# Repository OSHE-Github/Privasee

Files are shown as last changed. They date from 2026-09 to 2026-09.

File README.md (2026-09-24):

# Privasee

There are multiple different types of cameras. Detecting with them can be done in a combination of different ways. Some of these way include, but are not limited too detecting the infrared light pulses, reading the Radio Frequency and a handful of other waysPrivasee is a two semester project intended to locate and detect cameras. Additionally, the device itself aims to be low-cost, mobile, and efficient for detection. In other words, the device should be able to scan an area such as a hotel room and indicate to the user if there is a hidden camera. The basis of what to detect for hidden cameras boils down to infrared, radio frequencies, and possibly mac addresses. Infrared is a common trait of hidden cameras since this allows cameras to operate and record in low visibility. Radio frequency is used by hidden cameras to transmit data back to the owner. Mac addresses involve picking up packets sent in the area and displaying the signal strength and address of the device.



# Current State


The current prototype includes:
  
  - IR Detection
  - Mac Adress Reading 
  - RF detection (?)

  The system operates as a standalone or works with a laptop to detect cameras
  
# Features
## Infared Detection
  

Many imaging and sensing systems make use of infrared (IR) light for active detection. While standard full-color cameras rely on visible light, some systems emit IR pulses and measure their reflection to detect objects or changes in the environment. Other systems, such as thermal imaging, instead detect existing heat sources and do not require emitted signals.

This circuit focuses on detecting active IR pulses from an external source.

Using the logic shown in the diagram above, the system monitors for the presence of an incoming IR signal and responds when a valid pulse is detected.

The circuit below implements this detection mechanism. An IR sensor (photodiode or phototransistor) converts incoming infrared light into an electrical signal. This signal is then conditioned and amplified so it can be evaluated against a threshold.\

When the detected signal exceeds this threshold:
  - The circuit switches states
  - A control response is triggered
  - A buzzer is activated to indicate detection

This design allows the system to reliably detect IR pulses and convert them into a clear, real-time output signal. When integrated with a larger control loop, it can be used as an input for more complex sensing or decision-making systems.
  
  

## Radio Frequency
  Radio Frequency (RF) was chosen due to increasing amount of cameras connecting to Wifi. While connected to WiFi, cameras can capture vidoo and trasmit it. This makes it detectable for as it 
  emits oscilalitng EWF waves that can be picked up. For this semester of the project, the prototype aims to target active cameras transmitting over 2.4GHz.

  

### Antenna
  In order to start detecting signal a proper antenna is needed. The antenna will be responsible for picking up wifi signals that devices emit. In this case, the antenna must tuned to a
  resonance frequency of 2.4GHz. With proper tuning, the antenna will pick up these wifi signals more efficiently and this will result in a higher AC voltage.

### Diode Rectification
  Achieving high AC voltage make it much easier to amplify and notice difference in detection. A limiting factor of this AC voltage is that it is operating at 2.4GHz which is much more than
  what the LM358 can support. To amend this, a BAT41 diode was used to help rectify the AC voltage into DC voltage. Advantages of this include readable and processable voltage by the Op amp.
  Downsides of this diode involve voltage drops which results in a weaker signal. A capacitor and resistor is needed in parallel with the rectified diode voltage output in order to “hold” the
  DC voltage so it can be amplified by the OP Amp.

### Amplfication
  As mentioned earlier, amplification is needed to help create a more readable voltage. This it utilizing an LM358 Op amp in a non-inverting configuration. 
  
  RF Results

## MAC Address Reading
Many hidden cameras will connect to the internet to upload the videos/pictures they capture. The ESP32's built in WiFi Promiscuous mode can be used to capture packet information and do further analysis on packets in the area. This system only uses information available in IEEE 802.11 packet headers, such as the sending MAC address and data segment length. The ESP32 will also take an RSSI (Received Signal Strength Indicator) measurement when the packet is received. This data helps seperate each packet by a unique device identifier, and enables tracking of the changing signal stregth over time.
The ESP is unable to differentiate between device types by using this information, limiting this features ability to identify hidden cameras. Though this is the case, the MAC addresses and RSSI can be used to located devices in the area that are connected to the internet. 

# Tools Used

### Software
  Arduino IDE  
  Python  
  KiCad  
  OnShape  
  Git Desktop  

### Hardware
  Solder Iron Station  
  Wire Cutters  
  Wire Crimpers  

# Assembly Instructions

## RF

### Antenna
The SMA mount will be used as basis for the ground plane
Cut two lengths of copper wire to 33mm  
Cut longer than intended length adjustments/tuning can be made afterwords  
Solder one length of the copper wire to the signal pin forming a 90 degree angle  
Solder another length to the SMA mount leg pointing in the opposite direction of the signal pin  

### Board Assembly
Using the schematic for RF assemble the parts on to the protoboard  
Minimize amount of solder used components connecting into V+  
This includes the antenna, BAT41 diode, 1nF capacitor, 1Mohm resistor, and LM358 Op amp  

# Other catagories

### RF Flaws
A big issue with the RF side of this project revolved around a poor testing environment. The testing environment of RF was near an oscilloscope scope which constantly emitted EMF waves. These radiating waves from the oscilloscope cause the antenna on the breadboard to pick up a much stronger signal that what was expected on a 2.4ghz band. This error was caught later on in the semester and resulted in a more rushed prototype of what is currently featured above. While the concept of RF detection is proved, there are underdeveloped areas of RF which include antenna creation and op amp gain. Additionally factors such as parasitic capacitance and type of boards used were not analyzed as well.

The current graph shows some post error data of the current prototype. While this does display a correlation of RF being detected, the gain actual gain is really low. This is mainly due to the BAT41 diode used which did rectify the voltage but resulted in a 0.3V drop. Due to passive antennas not outputting much voltage, there was not a large amount of rectified voltage to be amplified by the op amp. 

#Appendex
- [Bill of Materials (BOM)](Documentation/BOM.md)

# Refrences
[1] “IR cameras - how they work and how to use them,” Sensorland.com, 2026. https://www.sensorland.com/HowPage105.html (accessed Apr. 20, 2026).

‌

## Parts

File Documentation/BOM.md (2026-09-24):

# Bill of Materials (BOM)

This Bill of Materials summarizes all components required to assemble the Privasee Device.

---

## Main Board Module

| # | Part Name | Individual Cost | QTY | Total Cost | Link |
| - | --- | --- | --- | --- | ---- |
| 1 | ESP32-C6 Dev Board | $8.00 | 1 | $8.00 | https://www.digikey.com/en/products/detail/espressif-systems/ESP32-C6-DEVKITM-1-N4/18667011 |
| 2 | Micro SD Breakout | $7.50 | 1 | $7.50 | https://www.digikey.com/en/products/detail/adafruit-industries-llc/254/5761230 |
| 3 | Switch | $0.36 | 1 | $0.36 | https://www.digikey.com/en/products/detail/same-sky-formerly-cui-devices/SLW-129956-4A-RA-N-D/24399223 |
| 4 | 3.3V Buck Booster | $3.12 | 1 | $3.12 | https://www.digikey.com/en/products/detail/dfrobot/DFR0568/9559258 |
| 5 | AA Battery Holder | $1.80 | 1 | $1.80 | https://www.digikey.com/en/products/detail/mpd-memory-protection-devices/BC2AAW/2190080 |

**Subtotal: $20.78**

---

## RF Module

| # | Part Name | Individual Cost | QTY | Total Cost | Link |
| - | --- | --- | --- | --- | ---- |
| 1 | Antenna Mount | $3.86 | 1 | $3.86 | https://www.digikey.com/en/products/detail/molex/0732511153/11305709 |
| 2 | Copper Wire Spool | ~$7.00 | 1 | ~$7.00 | Lab Resource |
| 3 | SMA M-M Adapter | $6.95 | 1 | $6.95 | https://www.amazon.com/dp/B0BWJGQC9M |
| 4 | BAT41 Diode | $0.15 | 2 | $0.30 | https://www.digikey.com/en/products/detail/stmicroelectronics/BAT41/603518 |
| 5 | 1nF Capacitor | $0.38 | 1 | $0.38 | https://www.digikey.com/en/products/detail/kemet/C320C102K3G5TA/6656382 |
| 6 | 1M Resistor | $0.10 | 1 | $0.10 | https://www.digikey.com/en/products/detail/stackpole-electronics-inc/CF14JT1M00/1741316 |
| 7 | 10k Resistor | $0.10 | 1 | $0.10 | https://www.digikey.com/en/products/detail/stackpole-electronics-inc/CF14JT10K0/1741265 |
| 8 | 1k Resistor | $0.10 | 1 | $0.10 | https://www.digikey.com/en/products/detail/stackpole-electronics-inc/CF14JT1K00/1741314 |
| 9 | Header Pin Pack | $3.29 | 1 | $3.29 | https://www.digikey.com/en/products/detail/aries-electronics/14-0600-21/49895 |
|10 | Protoboard | ~$5.00 | 1 | ~$5.00 | Lab Resource |

**Subtotal: ~$27.08**

---

## IR Module

| # | Part Name | Individual Cost | QTY | Total Cost | Link |
| - | --- | --- | --- | --- | ---- |
| 1 | Photodiode | $2.49 | 1 | $2.49 | https://www.digikey.com/en/products/detail/advanced-photonix/PDB-C134F/480578 |
| 2 | 25Ω Resistor | $0.10 | 1 | $0.10 | https://www.digikey.com/en/products/detail/stackpole-electronics-inc/MR3FT25L0/1650256 |
| 3 | 100Ω Resistor | $0.10 | 1 | $0.10 | (N/A) |
| 4 | 1MΩ Resistor | $0.10 | 1 | $0.10 | (N/A) |
| 5 | LM358 Op Amp | $0.99 | 1 | $0.99 | https://www.digikey.com/en/products/detail/texas-instruments/LM358N-NOPB/6264 |

**Subtotal: $3.78**

---

## Total Summary

| Category | Cost |
| --- | --- |
| Main Board | $20.78 |
| RF Module  | ~$27.08 |
| IR Module  | $3.78 |

### **Estimated Total Cost: ~$51.64**

---

## Notes

- RF subtotal corrected and expanded for missing components
- BAT41 diode quantity updated to match total cost
- Standardized resistor pricing where missing
- All links preserved for sourcing and procurement

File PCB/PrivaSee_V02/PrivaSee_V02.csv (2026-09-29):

Reference | Qty | Value | DNP | Exclude from BOM | Exclude from Board | Exclude from Simulation | Exclude from Position Files | Footprint | Datasheet
U6 | 1 | ESP32-C5-DevKitC-1 |  |  |  |  | ${EXCLUDE_FROM_POS_FILES} | PCM_Espressif:ESP32-C5-DevKitC-1 | https://docs.espressif.com/projects/esp-dev-kits/en/latest/esp32c5/esp32-c5-devkitc-1/user_guide.html
U4 | 1 | DFR0568 |  |  |  |  | ${EXCLUDE_FROM_POS_FILES} | Connector_PinSocket_2.54mm:PinSocket_2x02_P2.54mm_Vertical
U3 | 1 | 254 |  |  |  |  | ${EXCLUDE_FROM_POS_FILES} | Connector_PinHeader_2.54mm:PinHeader_1x08_P2.54mm_Vertical
U2 | 1 | LM358 |  |  |  |  | ${EXCLUDE_FROM_POS_FILES} | Package_DIP:DIP-8_W7.62mm_Socket | http://www.ti.com/lit/ds/symlink/lm2904-n.pdf
U1 | 1 | RC1602A |  |  | Excluded from board |  | ${EXCLUDE_FROM_POS_FILES} | Display:RC1602A | http://www.raystar-optronics.com/down.php?ProID=18
SW2 | 1 | SW_Push |  |  |  |  | ${EXCLUDE_FROM_POS_FILES} | Button_Switch_THT:SW_PUSH_6mm_H4.3mm
SW1 | 1 | Switch |  |  |  |  | ${EXCLUDE_FROM_POS_FILES} | Button_Switch_SMD:Nidec_Copal_CAS-120A | https://www.nidec-components.com/e/catalog/switch/cas.pdf
R9,R10 | 2 | 10k |  |  |  |  | ${EXCLUDE_FROM_POS_FILES} | Resistor_SMD:R_1206_3216Metric_Pad1.30x1.75mm_HandSolder
R8 | 1 | 100 ohm |  |  |  |  | ${EXCLUDE_FROM_POS_FILES} | Resistor_SMD:R_1206_3216Metric_Pad1.30x1.75mm_HandSolder
R7 | 1 | 10 |  |  |  |  | ${EXCLUDE_FROM_POS_FILES} | Resistor_SMD:R_1206_3216Metric_Pad1.30x1.75mm_HandSolder
R6 | 1 | RT0402BRE07100KL |  |  |  |  | ${EXCLUDE_FROM_POS_FILES} | Snapeda:RC0402N_YAG-L | RT0402BRE07100KL
R5 | 1 | 1 MOhm |  |  |  |  | ${EXCLUDE_FROM_POS_FILES} | Resistor_SMD:R_1206_3216Metric_Pad1.30x1.75mm_HandSolder
R4 | 1 | 100 Ohms |  |  |  |  | ${EXCLUDE_FROM_POS_FILES} | Resistor_SMD:R_1206_3216Metric_Pad1.30x1.75mm_HandSolder
R3 | 1 | 25 Ohms |  |  |  |  | ${EXCLUDE_FROM_POS_FILES} | Resistor_SMD:R_1206_3216Metric_Pad1.30x1.75mm_HandSolder
R2 | 1 | 470 Ohm |  |  |  |  | ${EXCLUDE_FROM_POS_FILES} | Resistor_SMD:R_1206_3216Metric_Pad1.30x1.75mm_HandSolder
R1 | 1 | 200 |  |  |  |  | ${EXCLUDE_FROM_POS_FILES} | Resistor_SMD:R_1206_3216Metric_Pad1.30x1.75mm_HandSolder
L1 | 1 | LQW15AN9N1H00D |  |  |  |  | ${EXCLUDE_FROM_POS_FILES} | Snapeda:INDC1006X60N
J7 | 1 | RF_TEST |  |  |  |  | ${EXCLUDE_FROM_POS_FILES} | TestPoint:TestPoint_THTPad_1.5x1.5mm_Drill0.7mm
J6 | 1 | IR_TEST |  |  |  |  | ${EXCLUDE_FROM_POS_FILES} | TestPoint:TestPoint_THTPad_1.5x1.5mm_Drill0.7mm
J5 | 1 | GND_TEST |  |  |  |  | ${EXCLUDE_FROM_POS_FILES} | TestPoint:TestPoint_Pad_1.0x1.0mm
J4 | 1 | VOUT_TEST |  |  |  |  | ${EXCLUDE_FROM_POS_FILES} | TestPoint:TestPoint_Pad_1.0x1.0mm
J3 | 1 | Conn_02x06_Odd_Even |  |  |  |  | ${EXCLUDE_FROM_POS_FILES} | Connector_PinHeader_2.54mm:PinHeader_2x06_P2.54mm_Vertical
J2 | 1 | Batt_Solder_Point |  |  |  |  | ${EXCLUDE_FROM_POS_FILES} | Connector_PinHeader_2.54mm:PinHeader_1x02_P2.54mm_Vertical
J1 | 1 | RFPC-SMA27-F |  |  |  |  | ${EXCLUDE_FROM_POS_FILES} | Snapeda:GRADCONN_RFPC-SMA27-F
D3 | 1 | Photodiode |  |  |  |  | ${EXCLUDE_FROM_POS_FILES} | Diode_THT:D_A-405_P2.54mm_Vertical_AnodeUp | https://www.diodes.com/assets/Datasheets/ds30396.pdf
D1 | 1 | BAT1504WH6327XTSA1 |  |  |  |  | ${EXCLUDE_FROM_POS_FILES} | JLCImport:BAT1504WH6327XTSA1 | https://wmsc.lcsc.com/wmsc/upload/file/pdf/v2/lcsc/2304061030_Infineon-Technologies-BAT1504WH6327XTSA1_C5380972.pdf
C3 | 1 | GJM1555C1H220FB01D |  |  |  |  | ${EXCLUDE_FROM_POS_FILES} | Snapeda:CAP_GJM1555C1H220FB01D_MUR-L | GJM1555C1H220FB01D
C2 | 1 | GJM1555C1H4R7CB01D |  |  |  |  | ${EXCLUDE_FROM_POS_FILES} | Snapeda:G-155_MUR-L | GJM1555C1H4R7CB01D
C1 | 1 | GJM1555C1HR22BB01D |  |  |  |  | ${EXCLUDE_FROM_POS_FILES} | Snapeda:CAPC1005X55N
BZ1 | 1 | Buzzer |  |  |  |  | ${EXCLUDE_FROM_POS_FILES} | Buzzer_Beeper:Buzzer_15x7.5RM7.6
BT1 | 1 | Battery |  |  | Excluded from board |  | ${EXCLUDE_FROM_POS_FILES} | Battery:BatteryHolder_Keystone_2462_2xAA

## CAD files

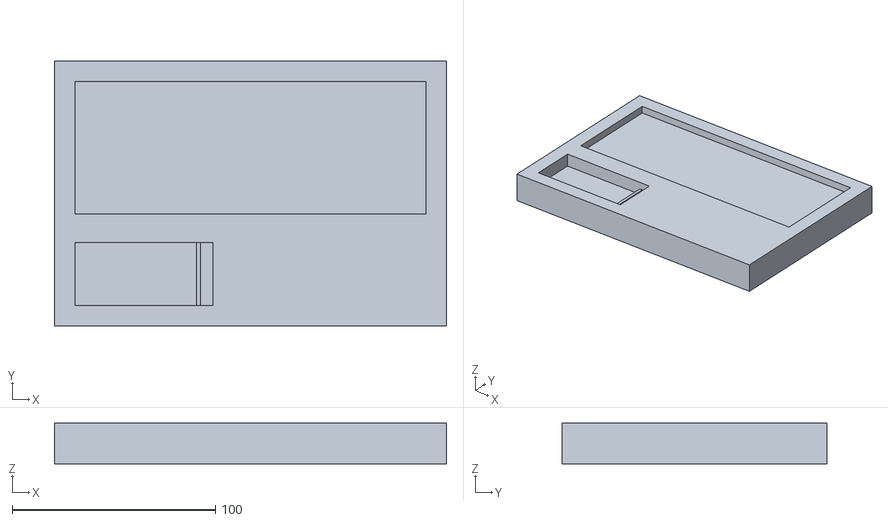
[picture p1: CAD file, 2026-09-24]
hardware/Breadboard_case.stl
193.1 x 130.4 x 20.0

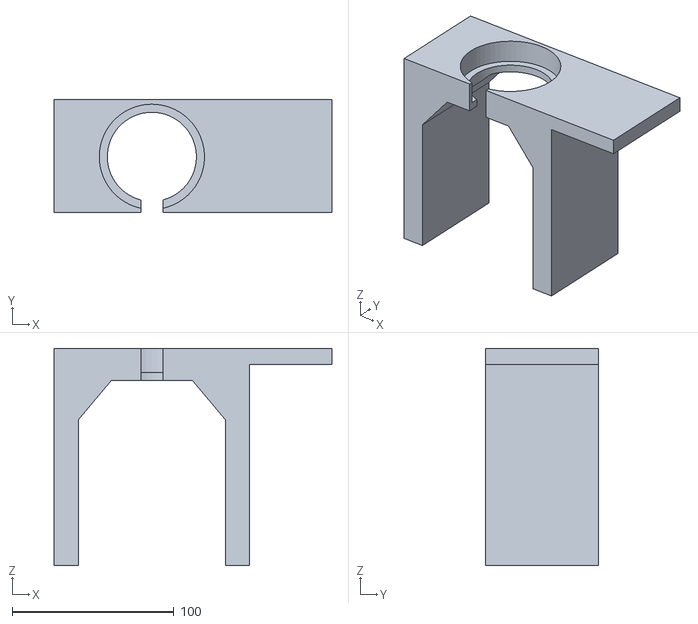
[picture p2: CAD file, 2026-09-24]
hardware/Magnfine_wave_amplifier.stl
171.7 x 69.7 x 134.3

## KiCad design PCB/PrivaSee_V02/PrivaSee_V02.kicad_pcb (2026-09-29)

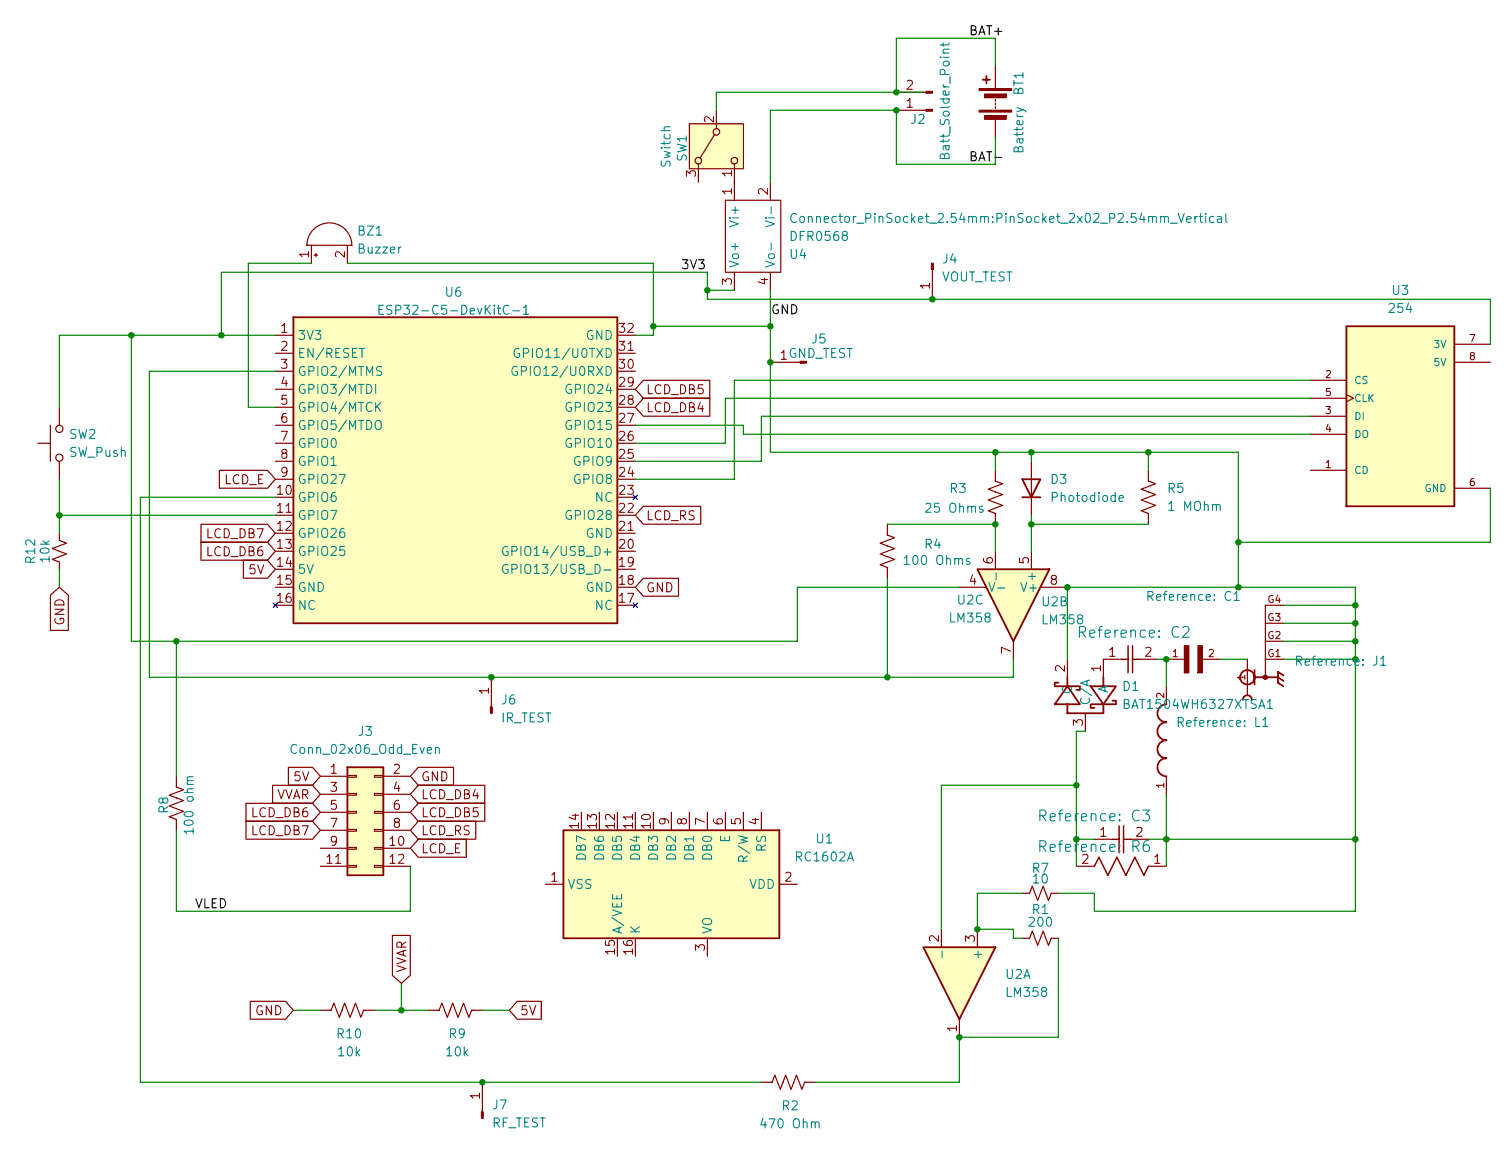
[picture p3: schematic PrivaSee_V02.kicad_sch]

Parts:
BT1: Battery; BatteryHolder_Keystone_2462_2xAA
BZ1: Buzzer; Buzzer_15x7.5RM7.6
C1: GJM1555C1HR22BB01D; CAPC1005X55N
C2: GJM1555C1H4R7CB01D; G-155_MUR-L
C3: GJM1555C1H220FB01D; CAP_GJM1555C1H220FB01D_MUR-L
D1: BAT1504WH6327XTSA1; Manufacturer Part BAT1504WH6327XTSA1; LCSC C5380972
D3: Photodiode; D_A-405_P2.54mm_Vertical_AnodeUp
J1: RFPC-SMA27-F; GRADCONN_RFPC-SMA27-F; PARTREV 1.0
J2: Batt_Solder_Point; PinHeader_1x02_P2.54mm_Vertical
J3: Conn_02x06_Odd_Even; PinHeader_2x06_P2.54mm_Vertical
J4: VOUT_TEST; TestPoint_Pad_1.0x1.0mm
J5: GND_TEST; TestPoint_Pad_1.0x1.0mm
J6: IR_TEST; TestPoint_THTPad_1.5x1.5mm_Drill0.7mm
J7: RF_TEST; TestPoint_THTPad_1.5x1.5mm_Drill0.7mm
L1: LQW15AN9N1H00D; INDC1006X60N
R1: 200; R_1206_3216Metric_Pad1.30x1.75mm_HandSolder
R2: 470 Ohm; R_1206_3216Metric_Pad1.30x1.75mm_HandSolder
R3: 25 Ohms; R_1206_3216Metric_Pad1.30x1.75mm_HandSolder
R4: 100 Ohms; R_1206_3216Metric_Pad1.30x1.75mm_HandSolder
R5: 1 MOhm; R_1206_3216Metric_Pad1.30x1.75mm_HandSolder
R6: RT0402BRE07100KL; RC0402N_YAG-L
R7: 10; R_1206_3216Metric_Pad1.30x1.75mm_HandSolder
R8: 100 ohm; R_1206_3216Metric_Pad1.30x1.75mm_HandSolder
R9, R10, R12: 10k; R_1206_3216Metric_Pad1.30x1.75mm_HandSolder
SW1: Switch; Nidec_Copal_CAS-120A
SW2: SW_Push; SW_PUSH_6mm_H4.3mm
U1: RC1602A
U2: LM358; DIP-8_W7.62mm_Socket
U3: 254; PinHeader_1x08_P2.54mm_Vertical; PARTREV Jul 31, 2013
U4: DFR0568; PinSocket_2x02_P2.54mm_Vertical
U6: ESP32-C5-DevKitC-1

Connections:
5V: J3.1, R9.2, U6.14 (5V)
/3V3: J4.1 (Pin_1_1), R8.1, SW2.2, U2.4 (V-), U3.7 (3V), U4.3 (Vo+), U6.1 (3V3)
/BAT+: BT1.1 (+), J2.2 (Batt+), SW1.2 (B)
/BAT-: BT1.2 (-), J2.1 (Batt-), U4.2 (Vi-)
/VLED: J3.12, R8.2
GND: BZ1.2 (-), C3.2, D1.2 (C), D3.2 (A), J1.G1, J1.G2, J1.G3, J1.G4, J3.2, J5.1 (Pin_1_1), L1.1, R3.1, R5.1, R6.1, R7.2, R10.1, R12.1, U2.8 (V+), U3.6 (GND), U4.4 (Vo-), U6.18 (GND), U6.32 (GND)
LCD_DB4: J3.4, U6.28 (GPIO23)
LCD_DB5: J3.6, U6.29 (GPIO24)
LCD_DB6: J3.5, U6.13 (GPIO25)
LCD_DB7: J3.7, U6.12 (GPIO26)
LCD_E: J3.10, U6.9 (GPIO27)
LCD_RS: J3.8, U6.22 (GPIO28)
unnamed: BZ1.1 (+), U6.5 (GPIO4/MTCK)
unnamed: C1.1, C2.2, L1.2
unnamed: C1.2, J1.1
unnamed: C2.1, D1.1 (A)
unnamed: C3.1, D1.3 (C/A), R6.2, U2.2 (-)
unnamed: D3.1 (K), R5.2, U2.5 (+)
unnamed: J6.1 (Pin_1_1), R4.2, U2.7, U6.3 (GPIO2/MTMS)
unnamed: J7.1 (Pin_1_1), R2.1, U6.10 (GPIO6)
unnamed: R1.2, R2.2, U2.1
unnamed: SW1.1 (C), U4.1 (Vi+)
unnamed: R1.1, R7.1, U2.3 (+)
unnamed: R3.2, R4.1, U2.6 (-)
unnamed: U3.5 (CLK), U6.26 (GPIO10)
unnamed: U3.2 (CS), U6.24 (GPIO8)
unnamed: U3.3 (DI), U6.25 (GPIO9)
unnamed: U3.4 (DO), U6.27 (GPIO15)
unnamed: R12.2, SW2.1, U6.11 (GPIO7)
VVAR: J3.3, R9.1, R10.2

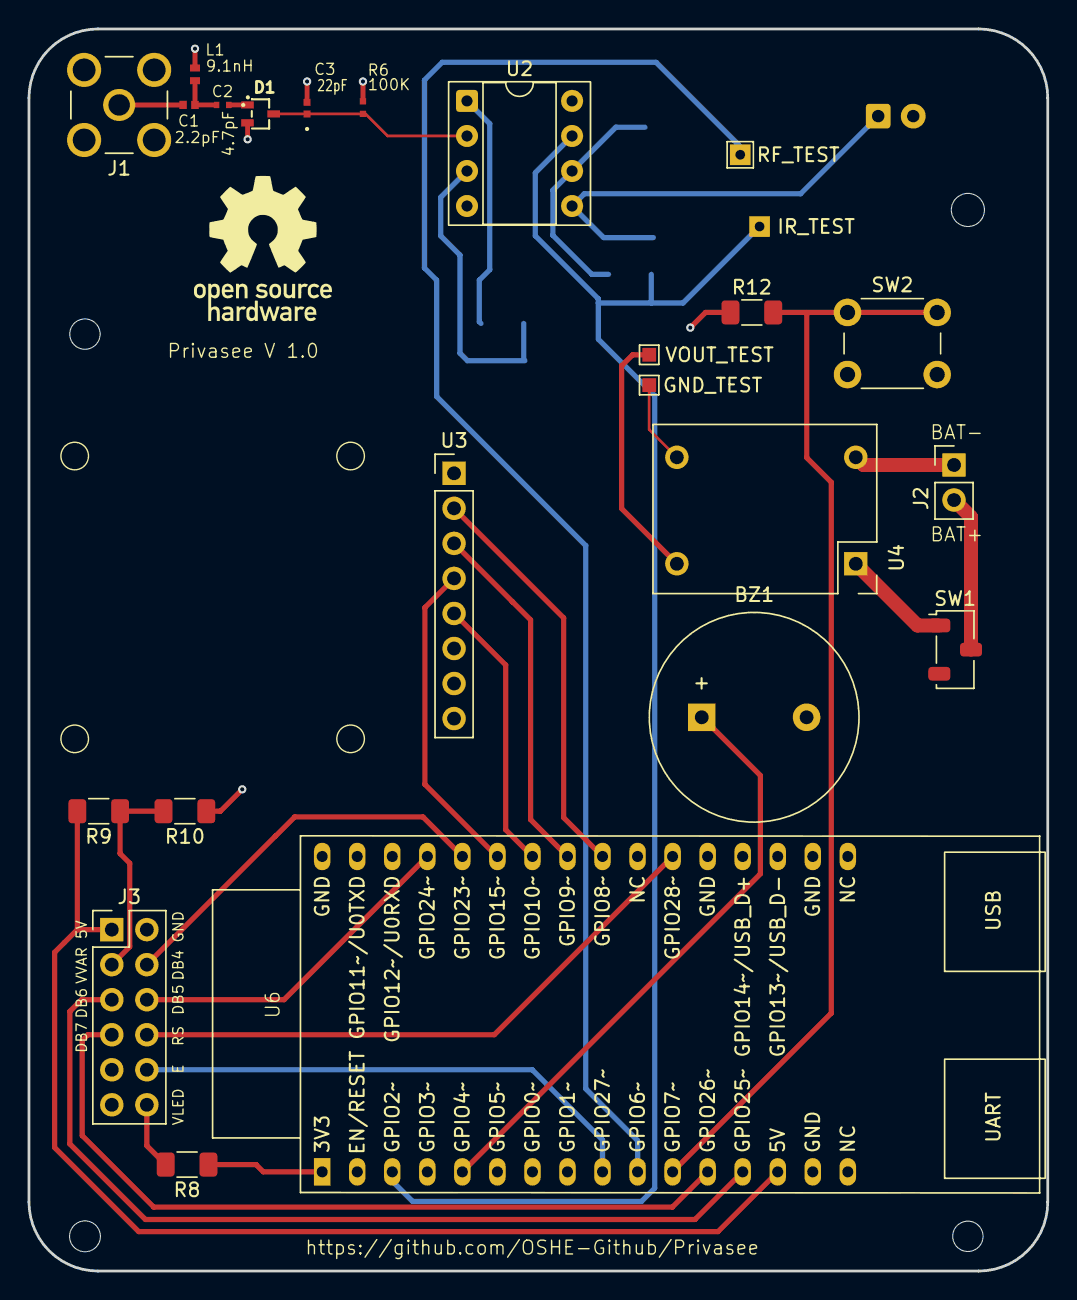
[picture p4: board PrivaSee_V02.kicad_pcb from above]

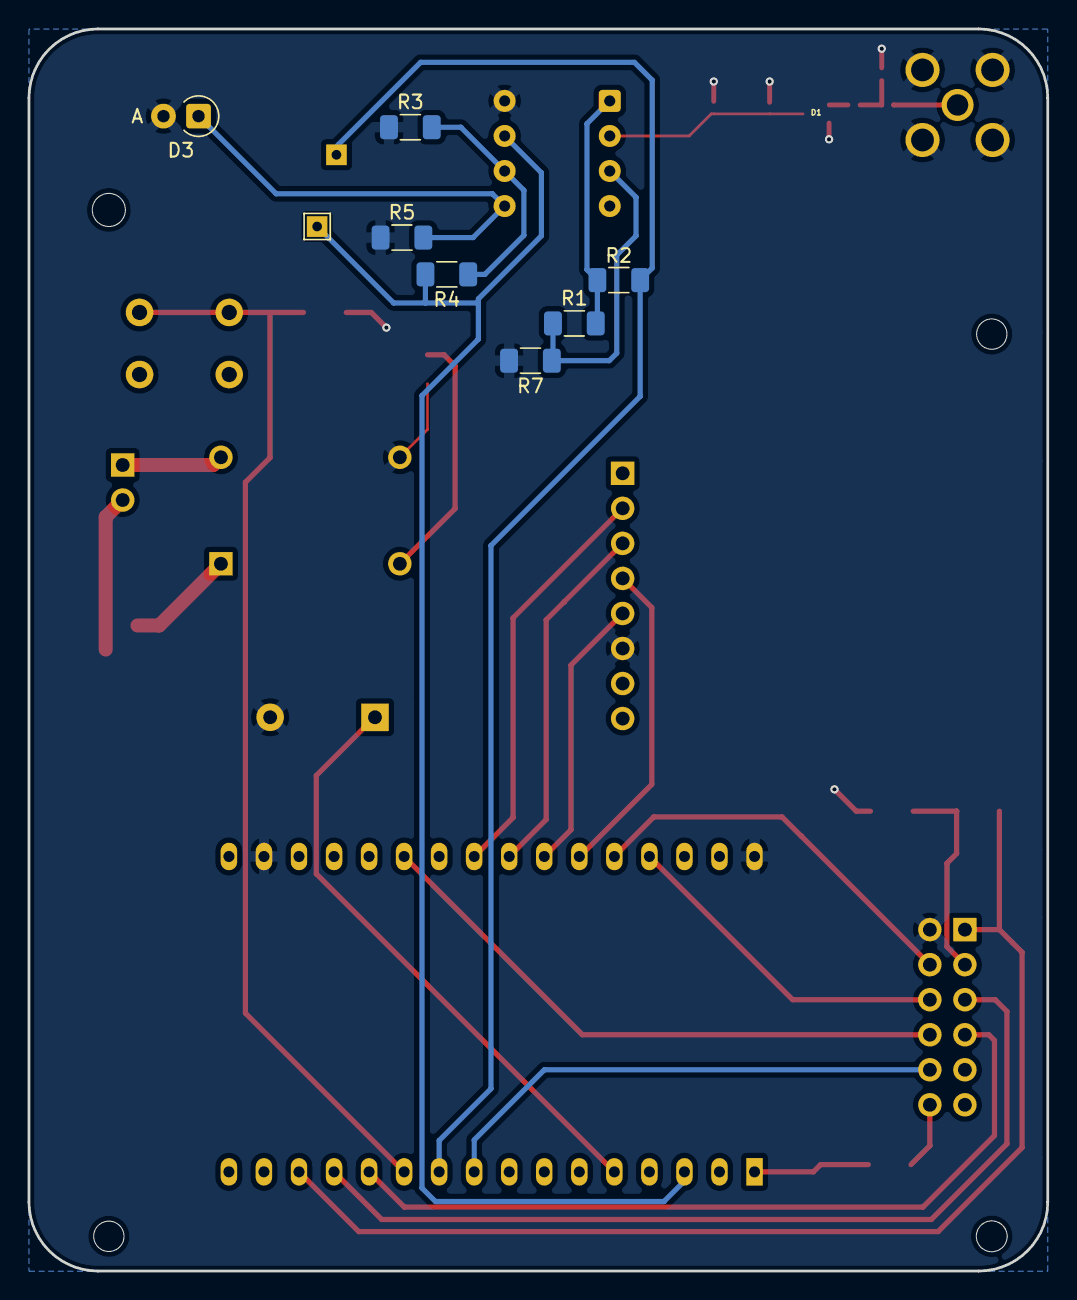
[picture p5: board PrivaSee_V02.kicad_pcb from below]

Board: 4 copper layers, 73.8 x 90.0 mm, 31 parts (8 on the bottom side), 30 nets.

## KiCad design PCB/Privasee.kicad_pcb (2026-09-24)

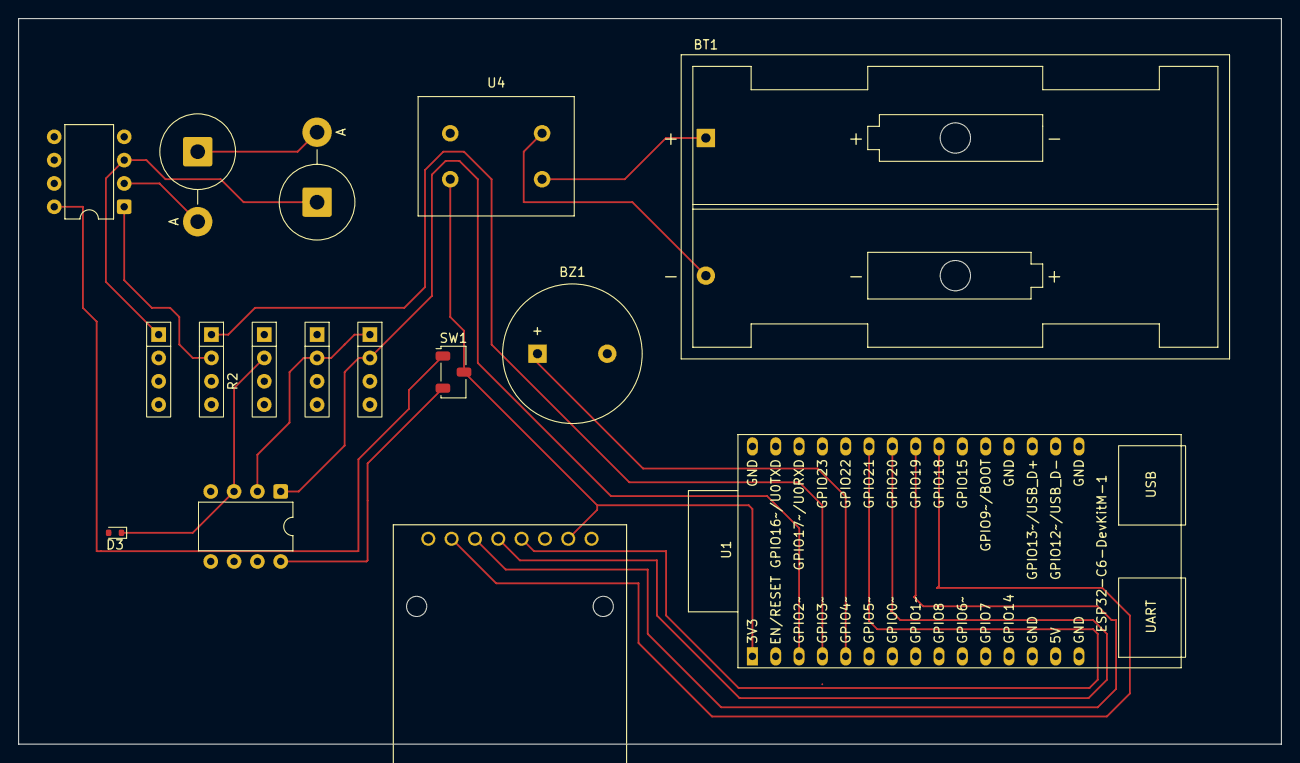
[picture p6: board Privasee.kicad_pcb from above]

Board: 2 copper layers, 137.5 x 79.0 mm, 16 parts (0 on the bottom side), 19 nets.

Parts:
BT1: Battery; BatteryHolder_Keystone_2462_2xAA
BZ1: Buzzer; Buzzer_15x7.5RM7.6
D1, D2: D; D_5KPW_P7.62mm_Vertical_AnodeUp
D3: Photodiode; D_SOD-523
R1: 1 M Ohm; R_Array_SIP4
R2: 470 Ohm; R_Array_SIP4
R3: 25 Ohms; R_Array_SIP4
R4: 100 Ohms; R_Array_SIP4
R5: 1 MOhm; R_Array_SIP4
SW1: (Generic toggle state switch); Nidec_Copal_CAS-120A
U1: ESP32-C6-DevKitM-1
U2, U5: LM358; DIP-8_W7.62mm
U3: 254; MODULE_254
U4: DFR0568; DFR0568_Module

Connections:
Antenna: D1.1 (K), D2.2 (A)
unnamed: BT1.1 (+), U4.3 (Vo+)
unnamed: BT1.2 (-), U4.4 (Vo-)
unnamed: BZ1.1 (+), U1.5 (GPIO4/MTMS)
unnamed: BZ1.2 (-), D3.2 (A), R1.2, R3.1, R5.1, U1.30 (GND), U2.4 (V-), U3.6 (GND), U4.2 (Vi-), U5.4 (V-)
unnamed: D1.2 (A), U5.2 (-)
unnamed: D2.1 (K), R1.1, U5.3 (+)
unnamed: D3.1 (K), R5.2, U2.3 (+)
unnamed: R2.2, U5.1
unnamed: SW1.3 (A), U2.8 (V+)
unnamed: SW1.2 (B), U1.1 (3V3), U3.7 (3V), U4.1 (Vi+)
unnamed: SW1.1 (C), U5.8 (V+)
unnamed: R4.2, U1.3 (GPIO2), U2.1
unnamed: R2.1, U1.4 (GPIO3)
unnamed: U1.22 (GPIO18), U3.2 (CS)
unnamed: U1.23 (GPIO19), U3.3 (DI)
unnamed: U1.24 (GPIO20), U3.4 (DO)
unnamed: U1.25 (GPIO21), U3.5 (CLK)
unnamed: R3.2, R4.1, U2.2 (-)

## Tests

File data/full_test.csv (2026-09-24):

Reading # | Camera 7 Inch | Camera 20 Inch | Camera 40 Inch | Camer 70 Inch | Camera 100 In | Light + Camera 7 In | No Light | Just Light | Box
1 | 740 | 773 | 658 | 677 | 669 | 1295 |  | 1224 | 251
2 | 739 | 774 | 653 | 675 | 668 | 1306 | 754 | 1223 | 253
3 | 739 | 771 | 657 | 678 | 675 | 1317 | 754 | 1220 | 251
4 | 741 | 772 | 655 | 677 | 668 | 1323 | 756 | 1213 | 251
5 | 738 | 772 | 657 | 685 | 668 | 1325 | 752 | 1203 | 251
6 | 741 | 772 | 654 | 678 | 671 | 1317 | 755 | 1196 | 250
7 | 743 | 773 | 656 | 677 | 671 | 1311 | 752 | 1186 | 250
8 | 738 | 772 | 652 | 682 | 670 | 1303 | 751 | 1208 | 249
9 | 741 | 772 | 656 | 678 | 671 | 1299 | 753 | 1229 | 250
10 | 735 | 771 | 656 | 681 | 670 | 1298 | 754 | 1226 | 250
11 | 741 | 774 | 656 | 679 | 669 | 1312 | 756 | 1218 | 251
12 | 741 | 772 | 654 | 679 | 667 | 1321 | 753 | 1209 | 249
13 | 741 | 771 | 659 | 678 | 672 | 1323 | 754 | 1199 | 251
14 | 737 | 773 | 656 | 681 | 669 | 1318 | 755 | 1195 | 250
15 | 737 | 773 | 656 | 679 | 670 | 1314 | 757 | 1196 | 249
16 | 740 | 773 | 658 | 680 | 668 | 1303 | 758 | 1198 | 250
17 | 742 | 777 | 655 | 679 | 670 | 1299 | 757 | 1223 | 252
18 | 740 | 772 | 656 | 675 | 670 | 1295 | 752 | 1225 | 250
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

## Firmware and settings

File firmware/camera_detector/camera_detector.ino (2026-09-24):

#include <SD.h>
#include <SPI.h>
#include "WiFi.h"
#include "esp_wifi.h"

// Configs
const int serialInit = 921600;

const int IRAnalogPin = 4;
const int buzz_pin = 6;

const int readEntries = 100;
const int sampleDelayUS = 50;   // microseconds between samples

// SD card
int sck = 22;
int miso = 21;
int mosi = 20;
int cs = 19;
char logFile[32];
char packetLog[32];

// Globals
int baseline = 0;
int noise = 0;
bool calibrated = false;
unsigned long lastIRcall = 0;

unsigned long lastTrigger = 0;
const int triggerCooldown = 500; // ms

// Wifi Globals/constants
// #define NUM_TRACKED_ADDR 10 unneeded atm
#define MAX_QUEUE_LENGTH 20
#define MIN_PACKET_LENGTH 32
#define PACKET_LED RGB_BUILTIN
#define PACKET_LED_PULSE 100
unsigned long packetLED_state; // time of last enable (ms)

// Filter for any wifi packet
wifi_promiscuous_filter_t filter = {
    .filter_mask = WIFI_PROMIS_FILTER_MASK_DATA | WIFI_PROMIS_FILTER_MASK_MGMT | WIFI_PROMIS_FILTER_MASK_CTRL,
};

typedef struct {
  uint8_t mac_addr[6];
  int32_t rssi;
  uint32_t length;
} PacketInfo;

// Queue for packet processing
QueueHandle_t packet_queue;

void setup() {
  Serial.begin(serialInit);
  pinMode(buzz_pin, OUTPUT);

  // SD card setup
  Serial.println("Initializing SPI...");
  if (SPI.begin(sck, miso, mosi, cs) == 0) {
    Serial.println("SPI init failed!");
  }
  Serial.println("Initializing SD card...");
  if (!SD.begin(cs)) {
    Serial.println("SD card failed!");
    //while (true); // stop here
  }
  Serial.println("SD card initialized.");
  
  uint8_t cardType = SD.cardType();

  if (cardType == CARD_NONE) {
    Serial.println("No SD card attached");
    return;
  }

  // find unused logfile name & save. 
  // will open/close upon each write
  Serial.println("Finding new IR log file");
  snprintf(logFile, sizeof(logFile), "/log_%02d.txt", 1);
  uint8_t i = 0;
  while (SD.exists(logFile) == 1) {
    i++;
    snprintf(logFile, sizeof(logFile), "/log_%02d.txt", i);
    if (i > 99) {
      Serial.println("LOGS ARE FULL. PLEASE CLEAR");
      snprintf(logFile, sizeof(logFile), "/log_%02d.txt", 0);;
      break;
    }
    // delay(5);
  }
  Serial.println("empty IR log file found");

  // find second log file
  Serial.println("Finding new packet log file");
  snprintf(packetLog, sizeof(packetLog), "/packet_%02d.txt", 1);
  i = 0;
  while (SD.exists(packetLog) == 1) {
    i++;
    snprintf(packetLog, sizeof(packetLog), "/packet_%02d.txt", i);
    if (i > 99) {
      Serial.println("LOGS ARE FULL. PLEASE CLEAR");
      snprintf(packetLog, sizeof(packetLog), "/packet_%02d.txt", 0);;
      break;
    }
    // delay(5);
  }
  Serial.println("Packet log file found");

  // Write Header
  File file = SD.open(logFile, FILE_WRITE);
  if (file) {
    if (!file.println("time,value")) // CSV header
    {
      Serial.println("Failed to write headers");
    }
    file.flush();
  } else {
    Serial.println("Failed to open file.");
  }
  file.close();
  Serial.print(logFile);
  Serial.println(" created and initailized");

  // Calibrate IR
  Serial.println("Starting IR calibration...");
  calibrateIR();

  // Wifi Boilerplate
  WiFi.mode(WIFI_MODE_STA);
  esp_wifi_set_promiscuous(true);
  esp_wifi_set_promiscuous_filter(&filter);
  esp_wifi_set_promiscuous_rx_cb(&sniffer_callback);
  Serial.println(esp_wifi_start());
  
  // Initailize Queue
  packet_queue = xQueueCreate(MAX_QUEUE_LENGTH, sizeof(PacketInfo));
  if (packet_queue == NULL) {
    Serial.println("Error initalizing queue");
    while (true) {};
  }
  packetLED_state = 0;

  //funny stuff
  postCalibrate();
  Serial.println("Ready.");
  // while (true) {}
}

void loop() {
  //if (!calibrated) return;
  if ((millis() - packetLED_state) >= PACKET_LED_PULSE) {
    digitalWrite(PACKET_LED, LOW); 
  }

  if ((millis() - lastIRcall) > 50) {
    IR(); // TODO: Run every 50 ms
    Serial.println();
    lastIRcall = millis();
  }

  int packets_available = uxQueueMessagesWaiting(packet_queue);
  if (packets_available > 0) {
    // Read Packet
    PacketInfo pkt_info;
    if (xQueueReceive(packet_queue, &pkt_info, 0) == errQUEUE_EMPTY) {
      Serial.println("NOTHINH IN QUEUE. THIS SHOULDNT RUN. EVER.");
      return;
    }
    logPacket(pkt_info);
    printPacket(pkt_info);
  }
  
  //Serial.println("LOOP");
  // Serial.println();
}

void logPacket(PacketInfo pkt_info) {
  File file = SD.open(packetLog, FILE_APPEND);
  if (packetLog) {
    file.print("Packet | ");
    for (int i = 0; i < 6; i++) {
      file.print(pkt_info.mac_addr[i], HEX);
      file.print(" ");
    }
    file.print("| rssi: "); file.print(pkt_info.rssi); file.print(" length: "); file.print(pkt_info.length);
    file.println();
    file.flush();
  }
  file.close();
}

void printPacket(PacketInfo pkt_info) {
    // Display Individual Packets
    Serial.print("Packet | ");
    for (int i = 0; i < 6; i++) {
      Serial.print(pkt_info.mac_addr[i], HEX);
      Serial.print(" ");
    }
    Serial.print("| rssi: "); Serial.print(pkt_info.rssi); Serial.print(" length: "); Serial.print(pkt_info.length);
    Serial.println();
}

// Calibration function
void calibrateIR() {
  long sum = 0;
  int minVal = 4095;
  int maxVal = 0;

  for (int i = 0; i < 500; i++) {
    int val = analogRead(IRAnalogPin);
    sum += val;
    if (val < minVal) minVal = val;
    if (val > maxVal) maxVal = val;
    delay(2);
  }

  baseline = sum / 500;
  noise = maxVal - minVal;

  Serial.println("Calibration complete:");
  Serial.print("Baseline: "); 
  Serial.println(baseline);
  Serial.print("Noise: "); 
  Serial.println(noise);
  
  calibrated = true;
}   

// IR detection
bool IR() {
  int maxVal = 0;
  int minVal = 4095;

  for (int i = 0; i < readEntries; i++) {
    int val = analogRead(IRAnalogPin);

    if (val > maxVal) maxVal = val;
    if (val < minVal) minVal = val;

    //logData(micros(), val); // Fixed function call

    delayMicroseconds(sampleDelayUS);
  }

  int peak = maxVal - baseline;
  int dip = baseline - minVal;
  int threshold = noise * 5 + 100; // sensitivity
  /*Serial.print("Baseline: ");
  Serial.print(baseline);
  Serial.print(" | noise: ");
  Serial.print(noise);
  Serial.print(" | Peak: "); 
  Serial.print(peak);
  Serial.print(" | Dip: "); 
  Serial.print(dip);
  Serial.print(" | Threshold: "); 
  Serial.println(threshold);  
  */
  // Cooldown check (optional)
  // if (millis() - lastTrigger < triggerCooldown) return false;

  if (peak > threshold || dip > threshold) {
    Serial.println("DETECTED");

    Serial.print(baseline);
    Serial.print(" | noise: ");
    Serial.print(noise);
    Serial.print(" | Peak: "); 
    Serial.print(peak);
    Serial.print(" | Dip: "); 
    Serial.print(dip);
    Serial.print(" | Threshold: "); 
    Serial.println(threshold);  
    
    int buzzVal = (((double)baseline/maxVal)*256+10);
    if(dip * -1 > peak){
      buzzVal = ((double)minVal/baseline)*256+10;
    }
    if(buzzVal > 256){
      buzzVal = 256 ;
    }
    analogWrite(buzz_pin, buzzVal);

    Serial.print("Buzz: "); 
    Serial.println(buzzVal);  

    lastTrigger = millis();

    //name requested by Jordan Chopskie
    char Harold[1024];
    sprintf(Harold, " DETECTED IR \t max : %d | min : %d | base : %d", maxVal, minVal, baseline);

    logEvent(Harold);
    delay(25);
    return true;
  } else {
    analogWrite(buzz_pin, 0);
    return false;
  }
}

// Logging sensor values
void logData(unsigned long time, int value) {
  Serial.print(time);
  Serial.print(",");
  Serial.println(value);
  File file = SD.open(logFile, FILE_APPEND);
  if (logFile) {
    file.print(time);
    file.print(",");
    file.println(value);
    file.flush();
  }
  file.close();
}

// Logging events
void logEvent(const char* event) {
  File file = SD.open(logFile, FILE_APPEND);
  if (logFile) {
    file.print(millis());
    file.print(",EVENT:");
    file.println(event);
    file.flush();
  }
  file.close();
}

void sniffer_callback(void* buf, wifi_promiscuous_pkt_type_t type) {
  // This check is technically unneccicary due to filter config, but ima leave it in for now.
  if (type == WIFI_PKT_MISC) {
    Serial.println("MISC PACKET");
    return;
  }
  const wifi_promiscuous_pkt_t *ppkt = (wifi_promiscuous_pkt_t *)buf;
  // Make sure we wont go out of bounds
  int pkt_len = ppkt->rx_ctrl.sig_len;
  if (pkt_len <= MIN_PACKET_LENGTH) {
    return;
  }
  // Save info to tmp variable
  PacketInfo pkt_info;
  for (int i = 0; i < 6; i++) {
    // 10 is the offset of the source mac address in a MAC header
    pkt_info.mac_addr[i] = ppkt->payload[10+i];
  }
  pkt_info.rssi = ppkt->rx_ctrl.rssi;
  pkt_info.length = ppkt->rx_ctrl.sig_len;
  // push to queue
  xQueueSendToBackFromISR(packet_queue, &pkt_info, NULL);
  // toggle LED
  digitalWrite(PACKET_LED, HIGH); 
  packetLED_state = millis();

  // Serial.print("Packet | ");
  // for (int i = 0; i < 6; i++) {
  //   if (10+i >= ppkt->rx_ctrl.sig_len)
  //   {
  //     Serial.print("XX ");
  //     continue;
  //   }
  //   Serial.print(ppkt->payload[10+i], HEX);
  //   Serial.print(" ");
  // }
  // Serial.print("| rssi: "); Serial.print(ppkt->rx_ctrl.rssi); Serial.print(" length: "); Serial.print(ppkt->rx_ctrl.sig_len);
  // Serial.println();
}


//ignore
void postCalibrate(){
  analogWrite(buzz_pin, 255);
  delay(350);
  analogWrite(buzz_pin, 0); // stop
  delay(100);
  analogWrite(buzz_pin, 40);
  delay(350);
  analogWrite(buzz_pin, 0); // stop
  delay(100);
  analogWrite(buzz_pin, 100);
  delay(350);
  analogWrite(buzz_pin, 0); // stop
}

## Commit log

2026-09-24 Update Privasee PCB
    [Breadboard_case.stl, Magnfine_wave_amplifier.stl, PrivaSee_V02.kicad_pcb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]
2026-09-24 Fixed PCB Improt
    [PrivaSee_V02.kicad_pcb]
2026-09-24 Apply .gitignore to stop tracking ignored files
    [PrivaSee_V02.kicad_pcb]
2026-09-24 PCB appearance updates
    Updates to the silkscreen, footprint labels, and test points added
    [PrivaSee_V02.kicad_pcb, PrivaSee_V02.kicad_sch]
2026-09-24 Stackup/RF Changes
    Reassessed layer stackup. RF components are implemented/positioned correctly. Added values to passive RF components.
    [PrivaSee_V02.kicad_pcb]
2026-09-25 Removed Top Layer Ground Pour
    I dont think this is needed and I think this may degrade signal performance for RF
    [PrivaSee_V02.kicad_pcb]
2026-09-27 Minor Changes
    Removed traces that are connected via 3v3 net. Removed acute angle at L1. Adjusted spacing near LM358 power.
    [PrivaSee_V02.kicad_pcb]
2026-09-28 More edits
    Rerouting traces, pull down resistor added (I believe thats the right way for a pull down resistor). Creating more spacing between traces.
    [PrivaSee_V02.kicad_pcb, PrivaSee_V02.kicad_sch]
2026-09-29 Updates to PCB resize logo, reroute a couple traces under Eric's advice, etc
    [PrivaSee_V02.csv, PrivaSee_V02.kicad_pcb]
2026-10-06 Random Updates
    Random PCB Updates
2026-10-16 Schematic + RF Fixes
    Also changed button position
2026-10-20 trace changes
2026-10-20 trace adjustments
2026-10-20 more trace changes
2026-10-20 more tracing/changes
    teardrops added for signal pin. Screw mounts adjusted to 1.7mm. Sd breakout adjusted.
    In-progress
    -Button needs to be changed to match footprint. Lab buttons still work
2026-10-20 capacitor replacement
    handsolderable foot print
2026-10-20 button reverted
    button from lab will be used as of now since it doesnt require being held
2026-10-20 button replacement
    SPST NO implemented
2026-10-20 button update
2026-10-23 LM358 change
    Our current schematic has the symbols for V- and V+ swapped. Ground and power are now routed and traced properly
